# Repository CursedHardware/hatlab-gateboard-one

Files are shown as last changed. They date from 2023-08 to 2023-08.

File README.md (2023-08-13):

# HATLab Gateboard One

— Hackable MT7621(D)AT Reference Board for Geeks.

---

- [docs](docs)
- [OpenWrt] v21.02.5: [patches/openwrt/21.02.5](patches/openwrt/21.02.5)
- [U-boot] v2022.10: [patches/uboot/2022.10](patches/uboot/2022.10)

[OpenWrt]: https://openwrt.org
[U-boot]: https://en.wikipedia.org/wiki/Das_U-Boot

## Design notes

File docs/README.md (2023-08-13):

# Documentation

- Knowledge base: <http://open.hatlab.dbappsecurity.com.cn/gateboard-one> (Chinese)
- [Hardware function](hardware)
- [Schematic diagram](schematic)
- [Electrical parameters](ELECTRICAL.md)
- [Pre-compiled firmware](FIRMWARE.md)
- [WiFi/LTE module](MODULE.md)

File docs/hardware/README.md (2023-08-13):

# Hardware function

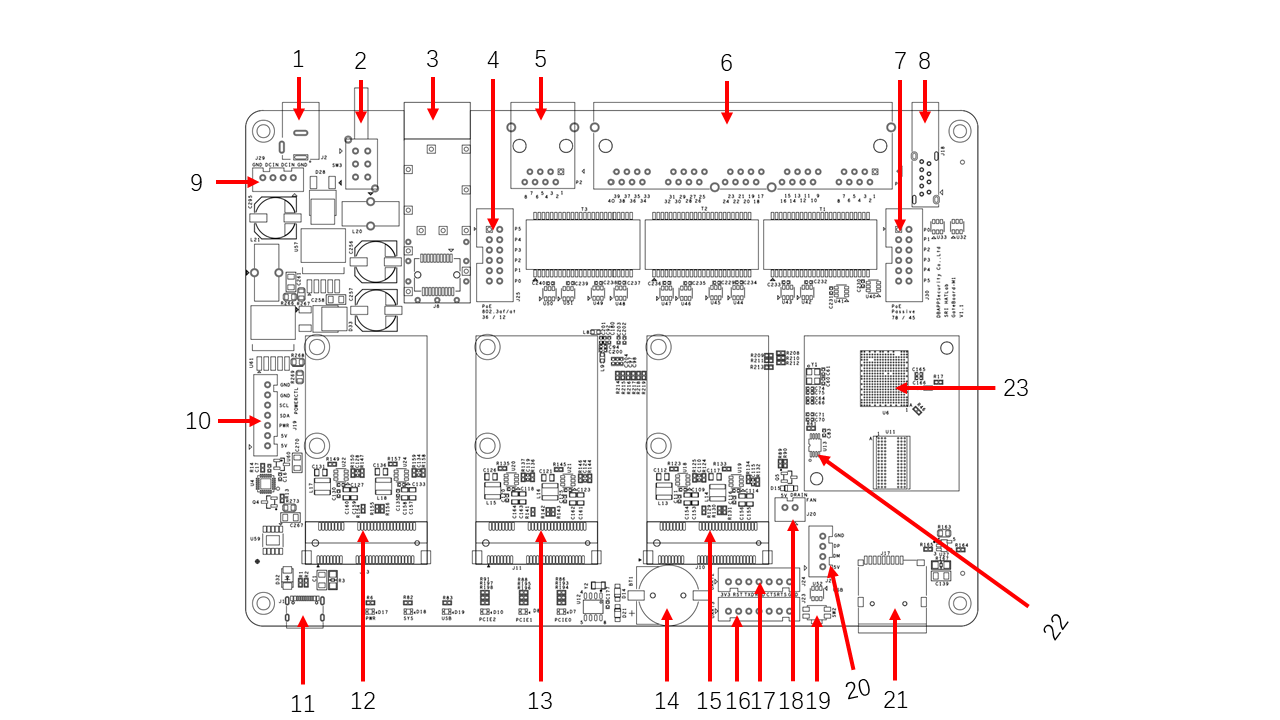
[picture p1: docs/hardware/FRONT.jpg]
Front


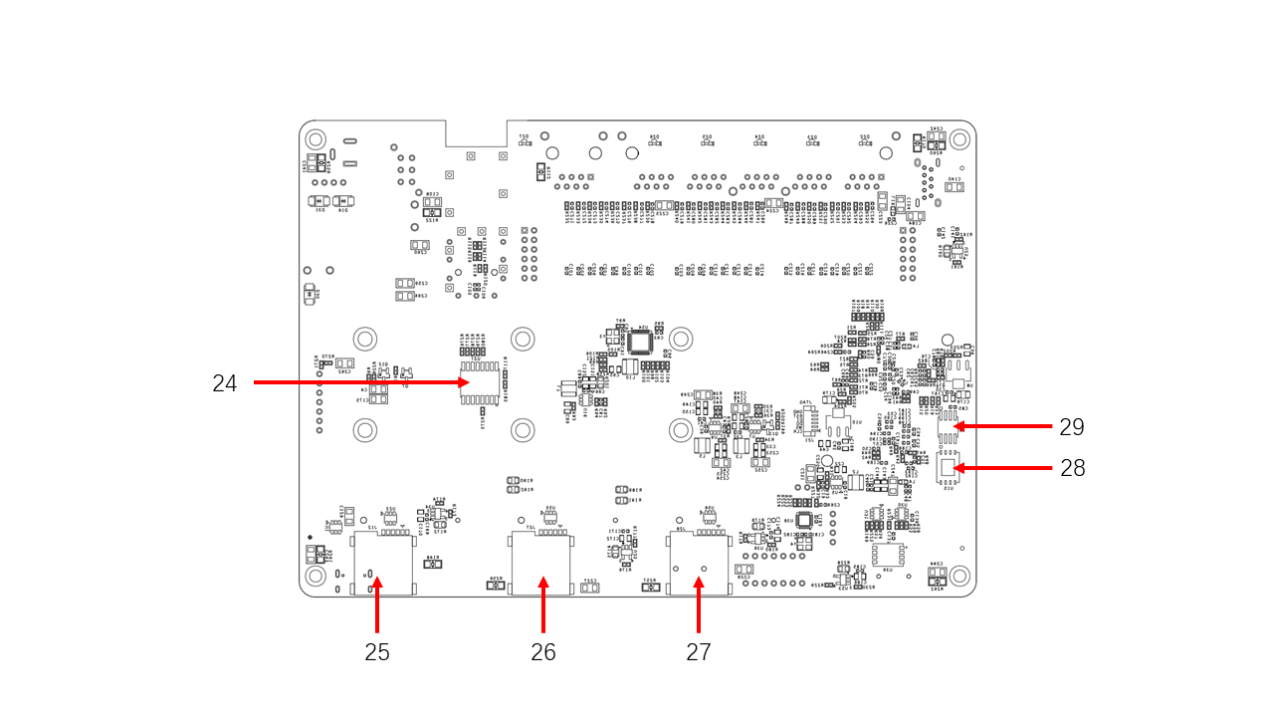
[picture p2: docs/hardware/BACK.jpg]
Back


1. [DC Power]
2. Power Switch
3. [SFP Combo]
4. [PoE IEEE]
5. [RJ45 Combo][SFP Combo]
6. [Ethernet] ports 1-5
7. [PoE Passive]
8. [USB 3.0]
9. External power supply interface
10. Function extension interface
11. Type-C (PD / [Serial])
12. [PCIe2]
13. [PCIe1]
14. RTC Battery (CR1220)
15. [PCIe0]
16. [Full-featured UART] 1
17. [Full-featured UART] 2
18. Fan Power Interface
19. Reset Power
20. Fan Control Interface
21. Pop-up [TF card slot]
22. Temperature Sensor [^temp-sensor]
23. [MT7621AT] Chip
24. GPIO extended chip
25. Pop-up [SIM card slot] 2
26. Pop-up [SIM card slot] 1
27. Pop-up [SIM card slot] 0
28. SPI NAND (Reserved)
29. BIOS NOR [^bios-flash]

[^temp-sensor]: On-board x1 Temperature Sensor, Used to collect the main control temperature.
[^bios-flash]: 512KB SPI Flash

[MT7621AT]: https://deviwiki.com/wiki/MediaTek_MT7621#MT7621AT
[DC Power]: ../schematic/README.md#power
[PoE IEEE]: ../pinout/README.md#poe-ieee
[PoE Passive]: ../pinout/README.md#poe-passive
[SFP Combo]: ../pinout/README.md#sfp
[Ethernet]: ../pinout/README.md#ethernet
[USB 3.0]: ../pinout/README.md#usb-30
[Serial]: ../schematic/README.md#usb-uart
[PCIe0]: ../schematic/README.md#pcie-0-connector
[PCIe1]: ../schematic/README.md#pcie-1-connector
[PCIe2]: ../schematic/README.md#pcie-2-connector
[Full-featured UART]: ../pinout/README.md#uart
[TF card slot]: ../pinout/README.md#tf-slot
[SIM card slot]: ../pinout/README.md#sim-slot

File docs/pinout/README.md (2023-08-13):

# PINOUT

## UART

> The UART Support RS232 / RS485

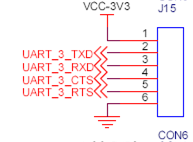
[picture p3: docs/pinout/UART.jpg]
UART


| # | Name |
| --: | --- |
| 1 | UART_3V3 |
| 2 | UART_TX  |
| 3 | UART_RX  |
| 4 | UART_CTS |
| 5 | UART_RTS |
| 6 | UART_GND |

## USB 3.0

> On-board x1 USB 3.0 Interface, Compatible USB 2.0, USB 1.1, Support USB-Hub Extending.

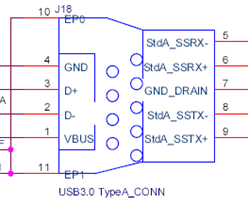
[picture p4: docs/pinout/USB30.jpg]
USB 3.0


| # | Name |
| --: | --- |
| 1 | VBUS |
| 2 | USB_D- |
| 3 | USB_D+ |
| 4 | GND |
| 5 | StdA_SSRX- |
| 6 | StdA_SSRX+ |
| 7 | GND_DRAIN  |
| 8 | StdA_SSTX- |
| 9 | StdA_SSTX+ |

## JTAG

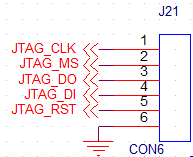
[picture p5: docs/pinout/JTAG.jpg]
JTAG


| # | Name |
| --: | --- |
| 1 | JTAG_CLK |
| 2 | JTAG_MS  |
| 3 | JTAG_DO  |
| 4 | JTAG_DI  |
| 5 | JTAG_RST |
| 6 | GND |

## PCIe

> There are 3 PCIe interfaces on board, all of which support PCIe2.0 x1 specification, and support PCIe function expansion cards such as PCIe to USB, PCIe to SATA, PCIe wired network card, PCIe wireless network card, etc.
>
> The 3 PCIe interfaces all support the expansion of the 4G/LTE module of the USB bus, and are connected with the onboard pop-up SIM card holder
>
> (Note: due to the BUG of the 7621 itself, only 2 modules can work at the same time when the dedicated module is not used).

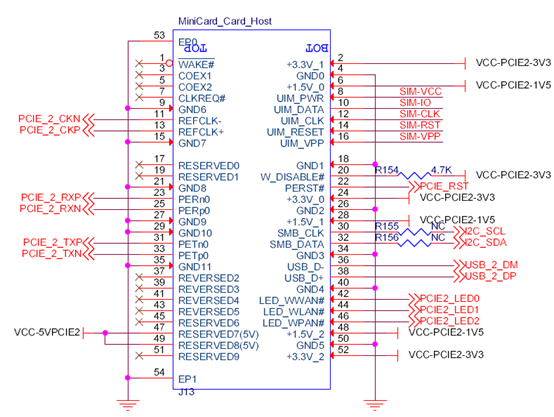
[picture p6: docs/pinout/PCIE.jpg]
PCIE


| # | Name (Standard) | Name (On board) |
| --: | --- | --- |
| 1 | WAKE# | NC |
| 2 | 3.3Vaux | VCC_3V3 |
| 3 | COEX1 | NC |
| 4 | GND | GND |
| 5 | COEX2 | NC |
| 6 | 1.5V | VCC_1V5 |
| 7 | CLKREQ# | NC |
| 8 | UIM_PWR | VCC_SIM |
| 9 | GND | GND |
|  10 | UIM_DATA | SIM_IO |
|  11 | REFCLK- | PCIE_CKN |
|  12 | UIM_CLK | SIM_CLK |
|  13 | REFCLK+ | PCIE_CKP |
|  14 | UIM_RESET | SIM_RESET |
|  15 | GND | GND |
|  16 | UIM_Vpp | SIM_VPP |
|  17 | _Reserved_ | NC |
|  18 | GND | GND |
|  19 | _Reserved_ | NC |
|  20 | W_DISABLE# | PU |
|  21 | GND | GND |
|  22 | PERST# | PCIE_RST |
|  23 | PERn0 | PCIE_RXP |
|  24 | 3.3Vaux | VCC_3V3 |
|  25 | PERp0 | PCIE_RXN |
|  26 | GND | GND |
|  27 | GND | GND |
|  28 | 1.5V | VCC_1.5V |
|  29 | GND | GND |
|  30 | SMB_CLK | I2C_SCL |
|  31 | PETn0 | PCIE_TXP |
|  32 | SMB_DATA | I2C_SDA |
|  33 | PETp0 | PCIE_TXN |
|  34 | GND | GND |
|  35 | GND | GND |
|  36 | USB_D- | USB_D- |
|  37 | GND | GND |
|  38 | USB_D+ | USB_D+ |
|  39 | 3.3Vaux | NC |
|  40 | GND | GND |
|  41 | 3.3Vaux | NC |
|  42 | LED_WWAN# | PCIE_LED0 |
|  43 | GND | NC |
|  44 | LED_WLAN# | PCIE_LED1 |
|  45 | _Reserved_ | NC |
|  46 | LED_WPAN# | PCIE_LED2 |
|  47 | _Reserved_ | VCC_5V |
|  48 | 1.5V | VCC_1.5V |
|  49 | _Reserved_ | VCC_5V |
|  50 | GND | GND |
|  51 | _Reserved_ | NC |
|  52 | 3.3Vaux | VCC_3V3 |

## SFP

> There is one SFP interface with plug-in detection on board, which is a mutually exclusive interface with RJ45 Combo.
>
> Compatible with ordinary GbE fiber optic modules.

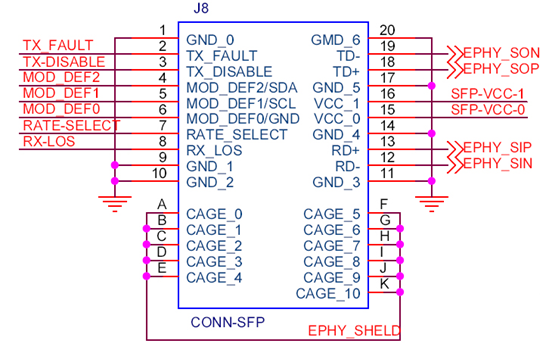
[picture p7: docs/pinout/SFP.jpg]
SFP


| # | Name |
| --: | --- |
| 1 | GND |
| 2 | TX_Fault |
| 3 | TX_disable  |
| 4 | MOD-DEF2 |
| 5 | MOD-DEF1 |
| 6 | MOD-DEF0 |
| 7 | Rate_Select |
| 8 | Rate_LOS |
| 9 | GND |
|  10 | GND |
|  11 | GND |
|  12 | EPHY_SIN |
|  13 | EPHY_SIP |
|  14 | GND |
|  15 | SFP_VCC0 |
|  16 | SFP_VCC1 |
|  17 | GND |
|  18 | EPHY_SOP |
|  19 | EPHY_SON |
|  20 | GND |

## Ethernet

> There are 6x GbE RJ45 network ports on board, all complying with IEEE1588-2008.

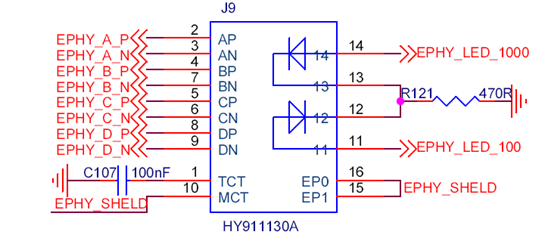
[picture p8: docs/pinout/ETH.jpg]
Ethernet


| # | Name |
| --: | --- |
| 1 | TCT |
| 2 | EPHY_A_P |
| 3 | EPHY_A_N |
| 4 | EPHY_B_P |
| 5 | EPHY_C_P |
| 6 | EPHY_C_N |
| 7 | EPHY_B_N |
| 8 | EPHY_D_P |
| 9 | EPHY_D_N |
|  10 | MCT |
|  11 | LED_YELLOW |
|  12 | GND |
|  13 | GND |
|  14 | LED_GREEN  |
|  15 | EPHY_SHELD |
|  16 | EPHY_SHELD |

## TF Slot

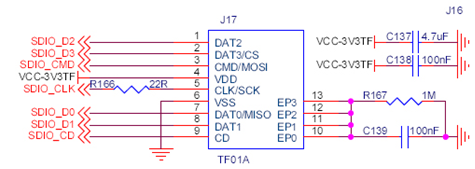
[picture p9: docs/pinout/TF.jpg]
TF Slot


| # | Name |
| --: | --- |
| 1 | SDIO_D2  |
| 2 | SDIO_D3  |
| 3 | SDIO_CMD |
| 4 | VCC_3V3  |
| 5 | SDIO_CLK |
| 6 | GND |
| 7 | SDIO_D0  |
| 8 | SDIO_D1  |
| 9 | SDIO_CD  |
|  10 | EP |
|  11 | EP |
|  12 | EP |
|  13 | EP |

## SIM Slot

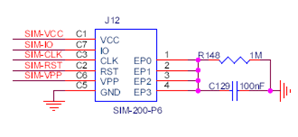
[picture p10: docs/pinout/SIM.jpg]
SIM Slot


| # | Name |
| --: | --- |
| 1 | SIM_VCC |
| 2 | SIM_IO  |
| 3 | SIM_CLK |
| 4 | SIM_RST |
| 5 | SIM_VPP |
| 6 | GND |

## Power Control

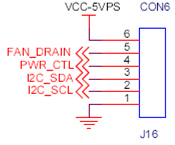
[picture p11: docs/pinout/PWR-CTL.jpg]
Power Control


| # | Name |
| --: | --- |
| 1 | GND |
| 2 | I2C_SCL |
| 3 | I2C_SDA |
| 4 | PWR_CTL |
| 5 | FAN_DRAIN |
| 6 | VCC |

\* PWR_CTL: high level is Power ON, low level is Power OFF.

## PoE IEEE

> Standard: 802.3af / 802.3at

## PoE Passive

> Standard: Passive

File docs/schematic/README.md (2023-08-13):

# Schematic diagram

## Power

> On-board x1 DC Power, Support 9-19V DC input.

No Public

## USB UART

> The USB Serial is [CH340N] chip

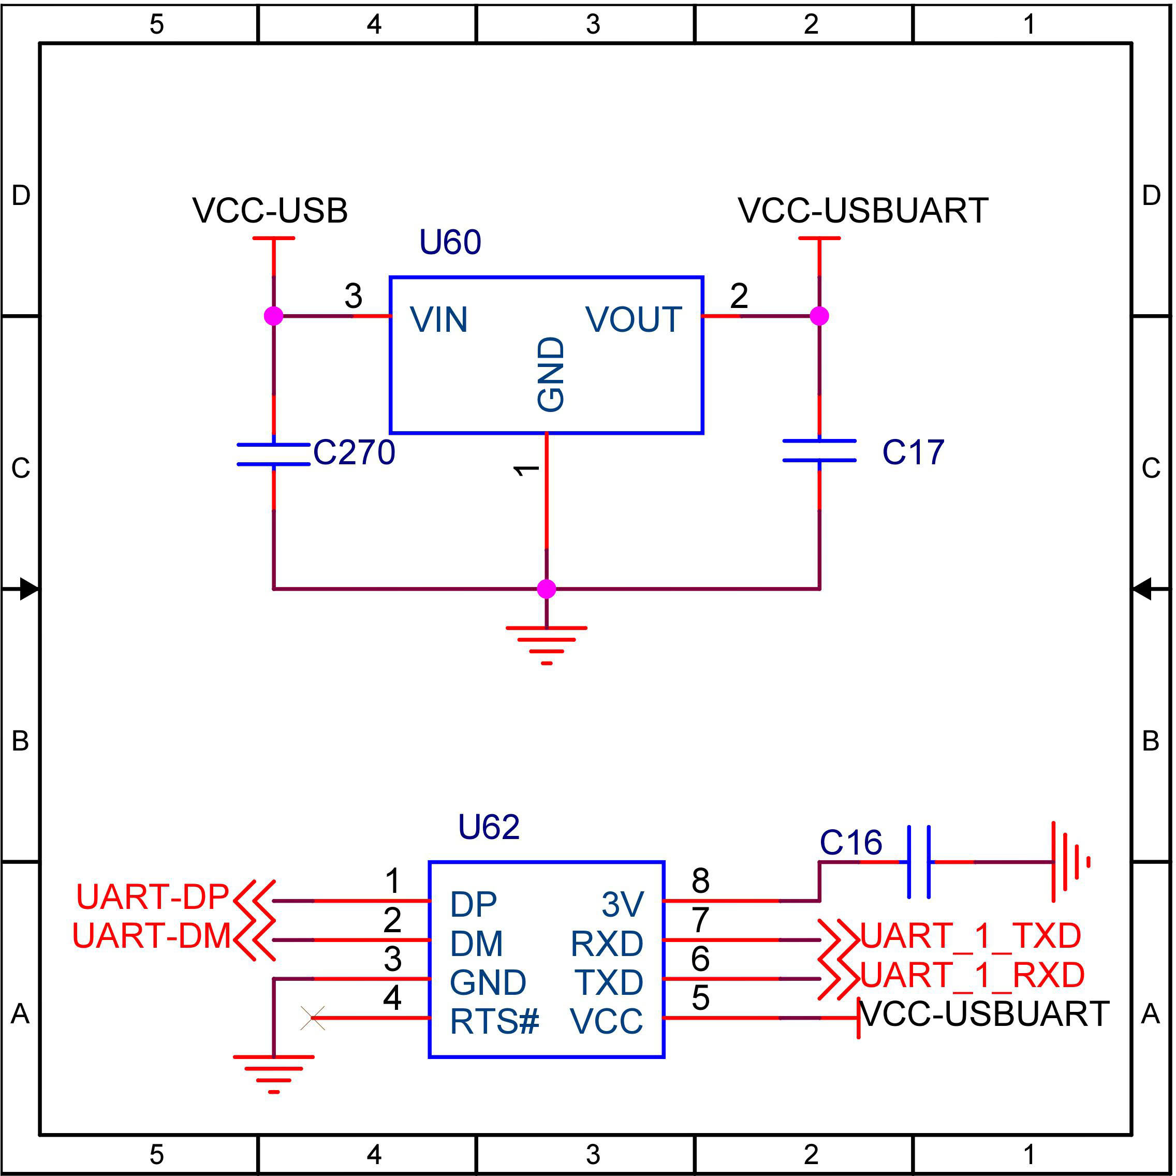
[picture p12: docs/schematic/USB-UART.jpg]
USB-UART


## SoC Config

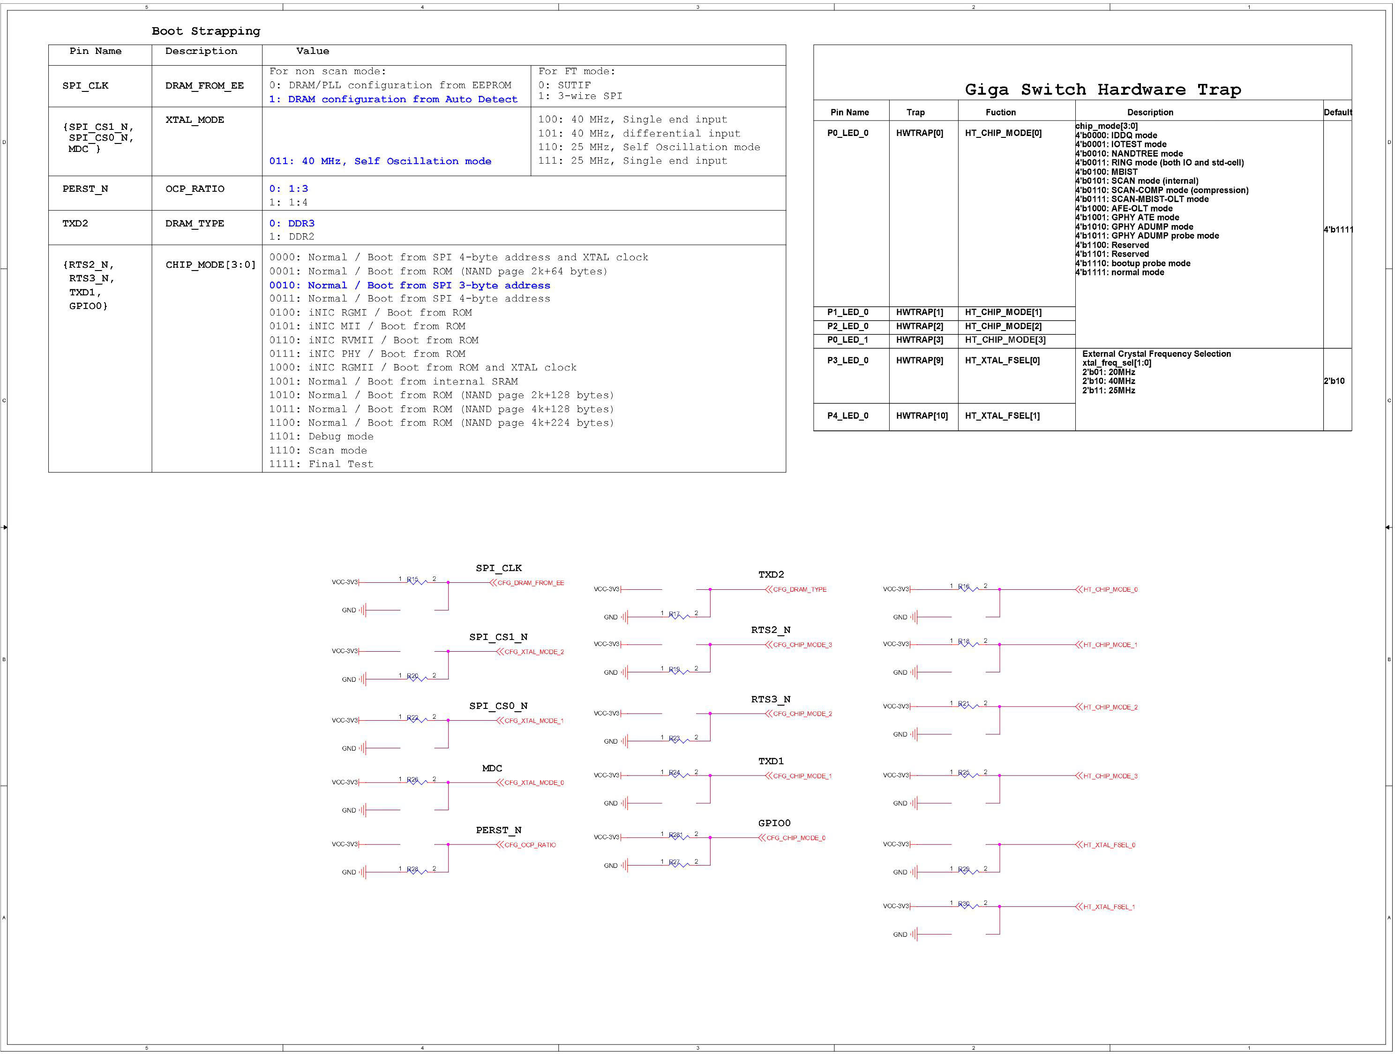
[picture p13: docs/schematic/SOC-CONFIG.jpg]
SOC-CONFIG


## SoC Power

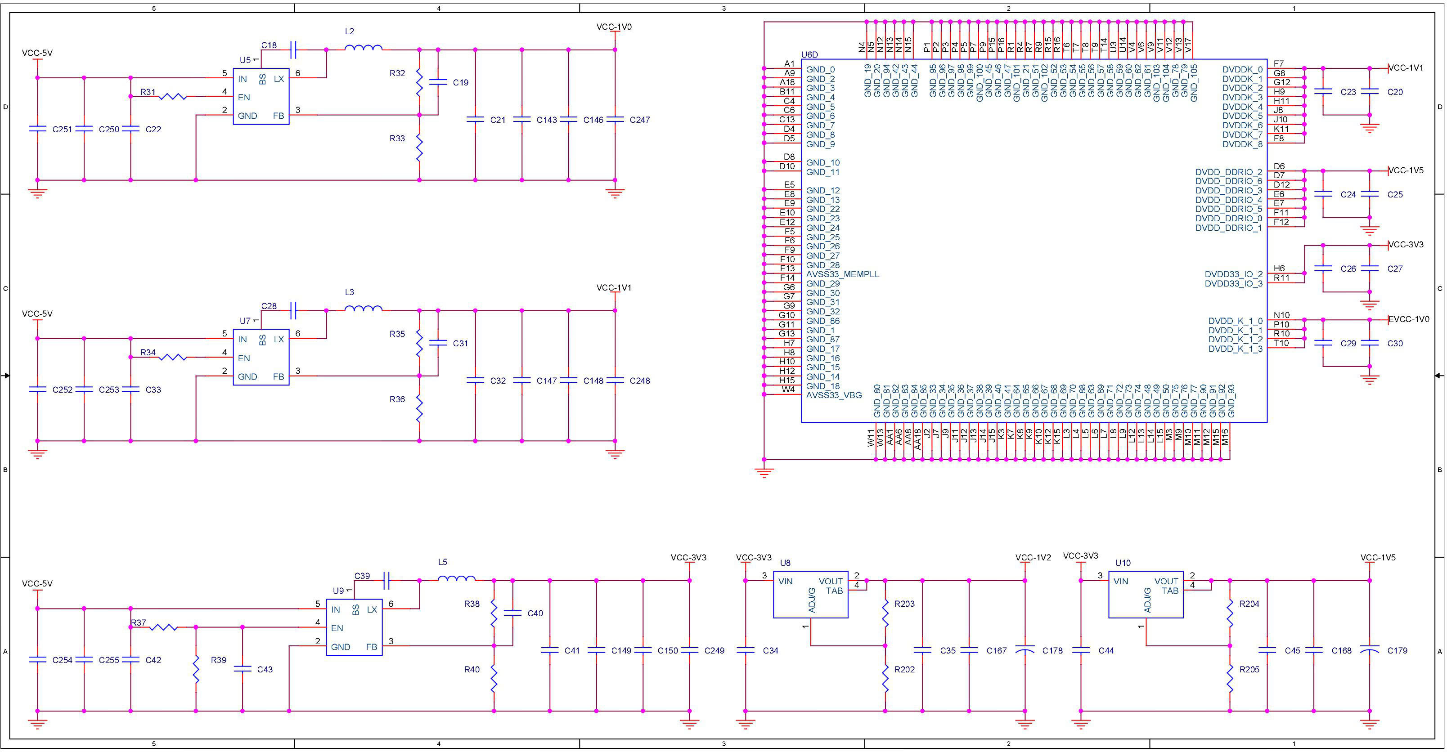
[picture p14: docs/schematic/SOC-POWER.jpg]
SOC-POWER


## SoC Memory

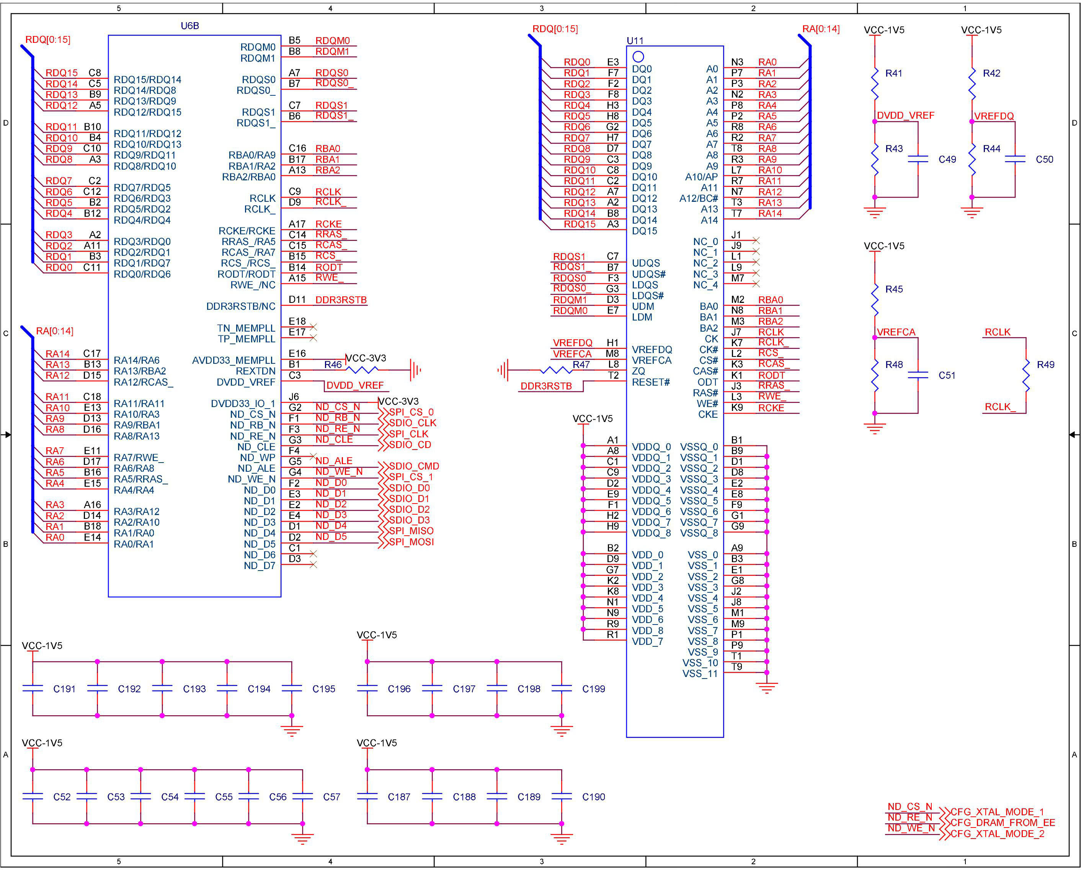
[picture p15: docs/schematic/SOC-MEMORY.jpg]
SOC-MEMORY


## SoC System/USB/PCIe

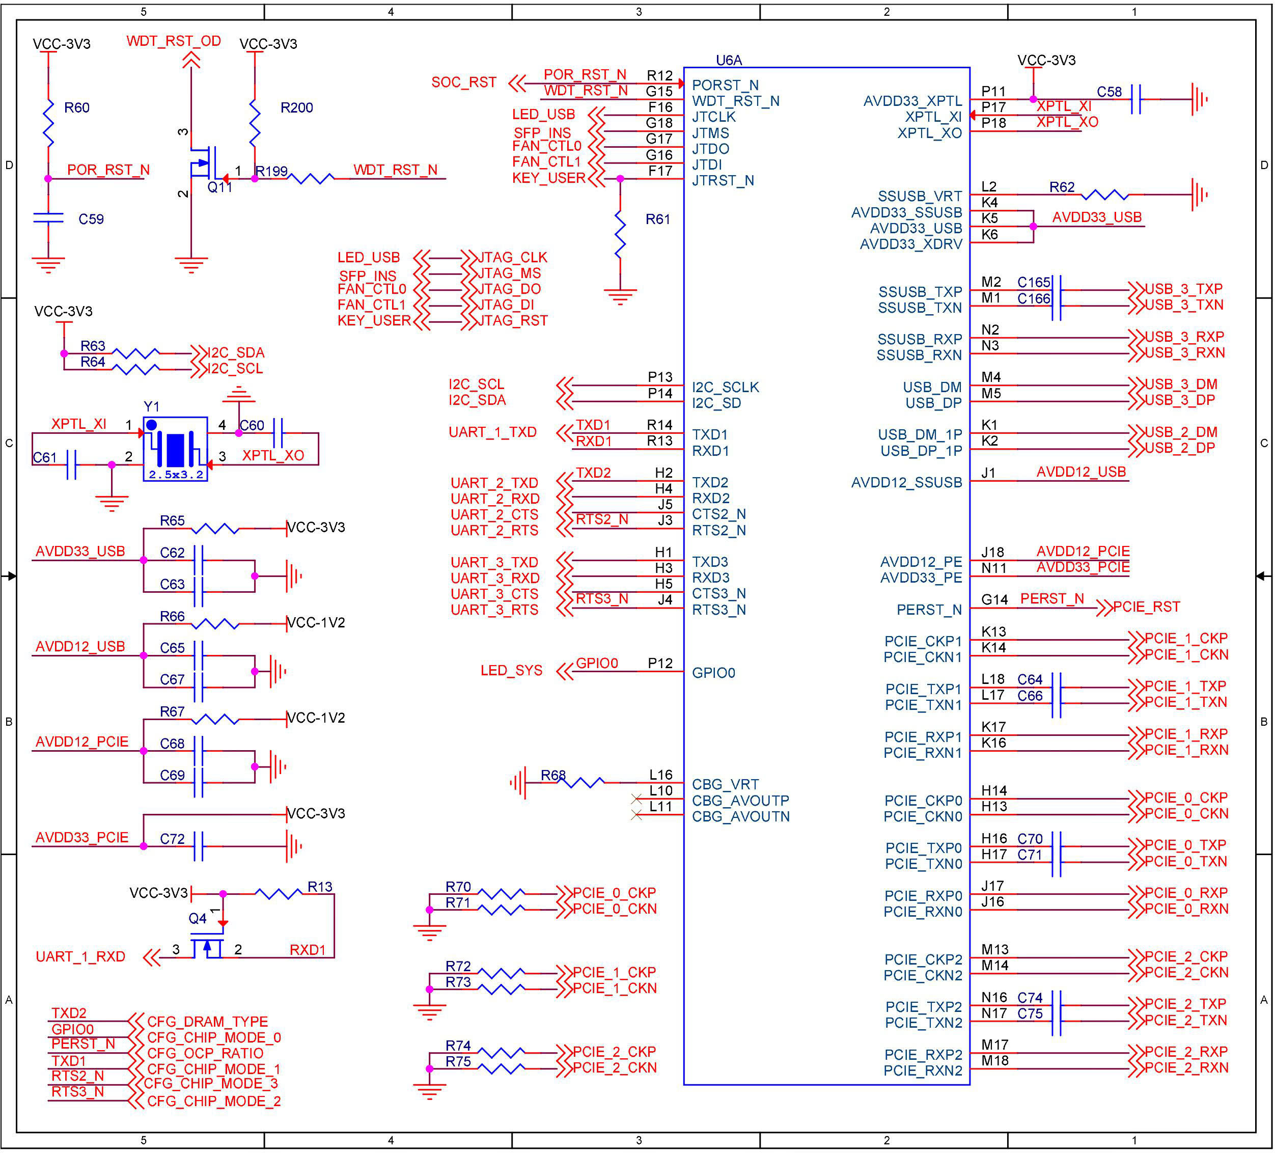
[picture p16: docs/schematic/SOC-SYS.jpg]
SOC-SYS


## SoC GSwitch/RGMII

No Public

## Perhipial

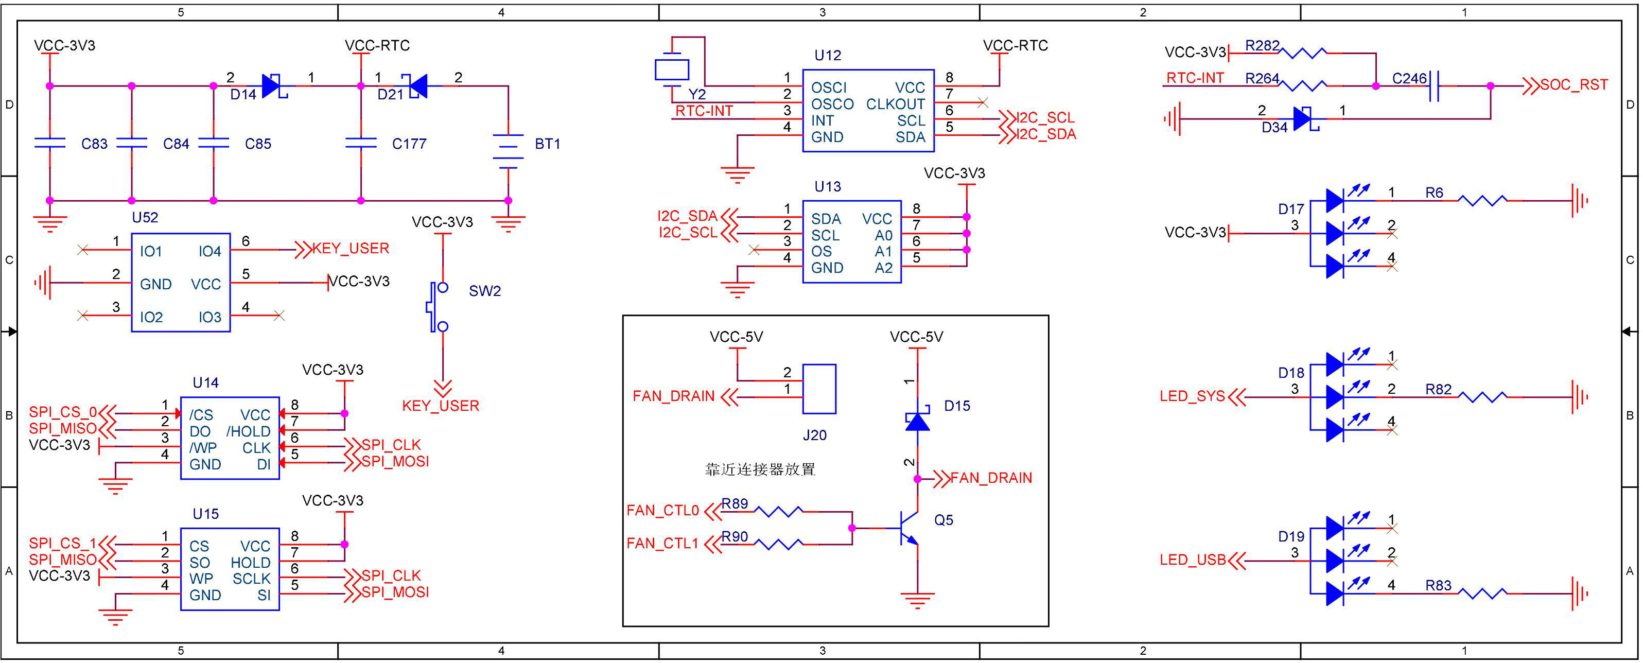
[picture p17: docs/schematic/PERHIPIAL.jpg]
PERHIPIAL


## External PHY

No Public

## USB Hub

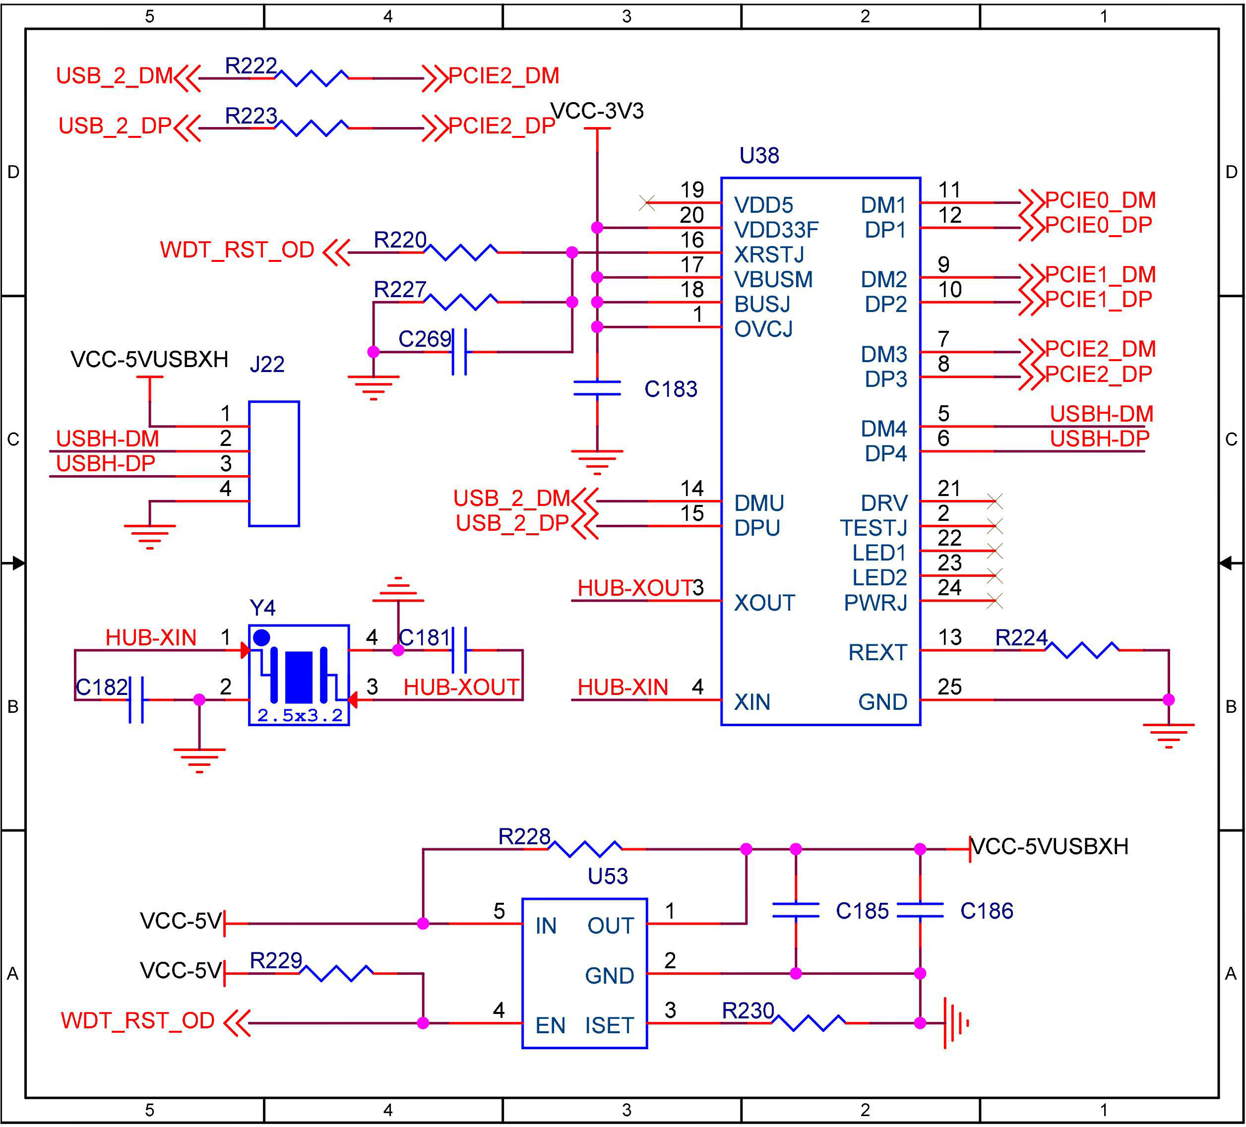
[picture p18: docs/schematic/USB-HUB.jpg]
USB-HUB


## Network (Connector)

No Public

## PCIe 0 (Connector)

> PINOUT: [PCIe]

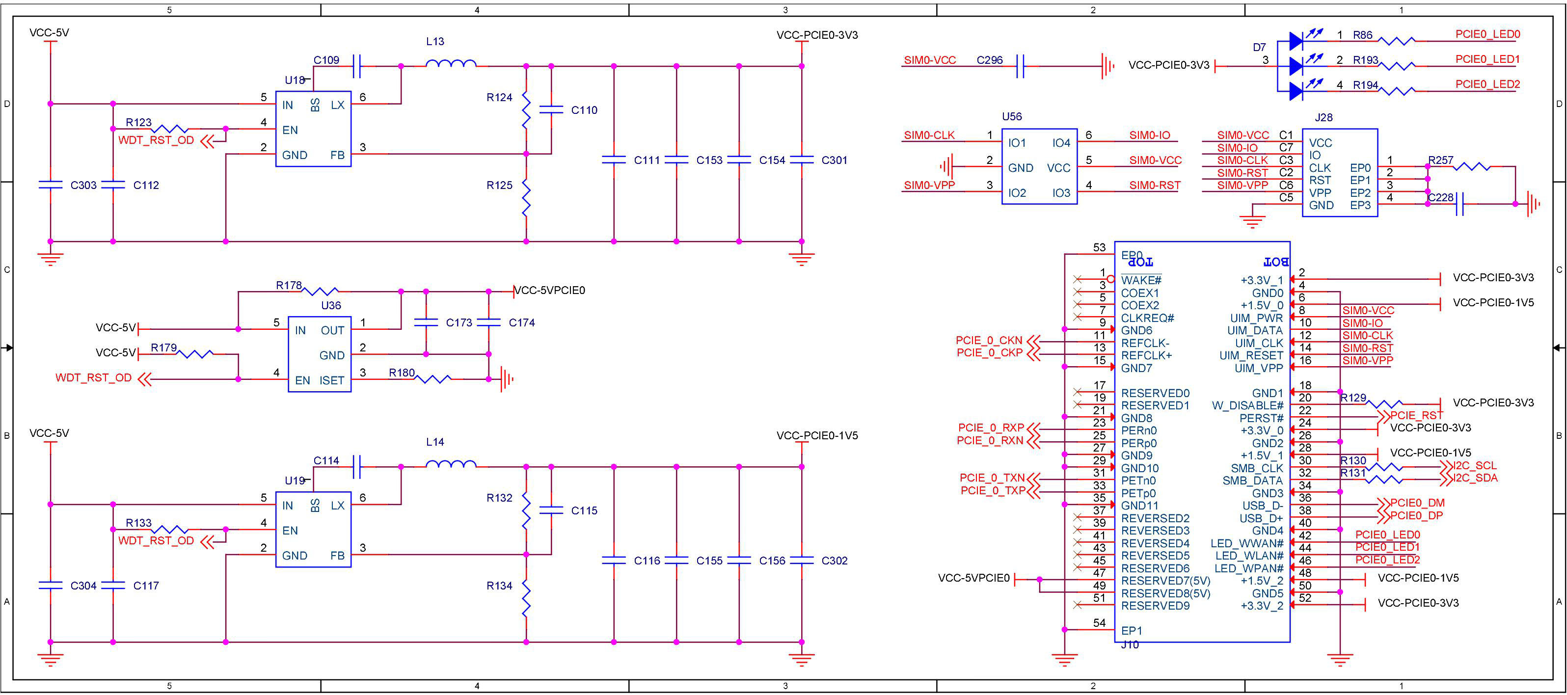
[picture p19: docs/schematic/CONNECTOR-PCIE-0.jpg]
CONNECTOR-PCIE-0


## PCIe 1 (Connector)

> PINOUT: [PCIe]

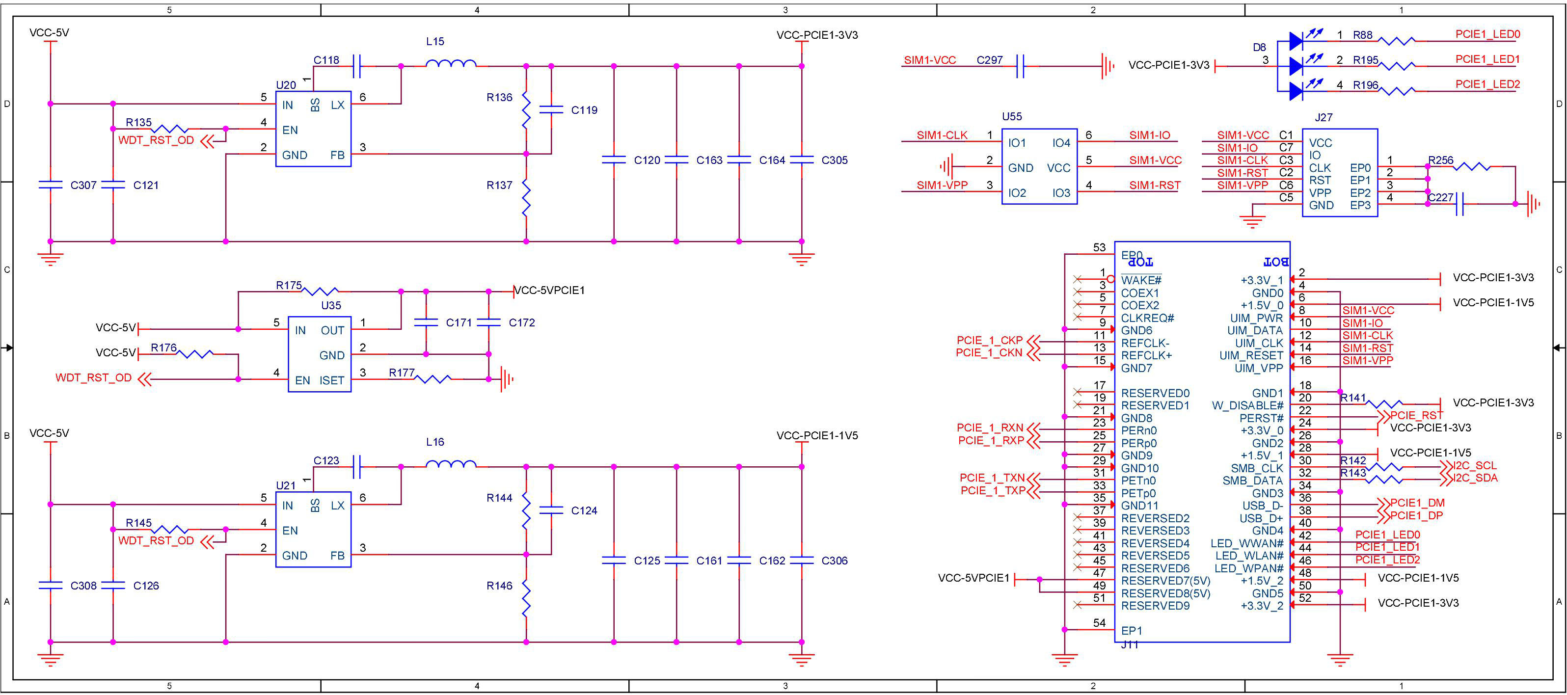
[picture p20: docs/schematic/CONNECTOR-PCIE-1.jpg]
CONNECTOR-PCIE-1


## PCIe 2 (Connector)

> PINOUT: [PCIe]

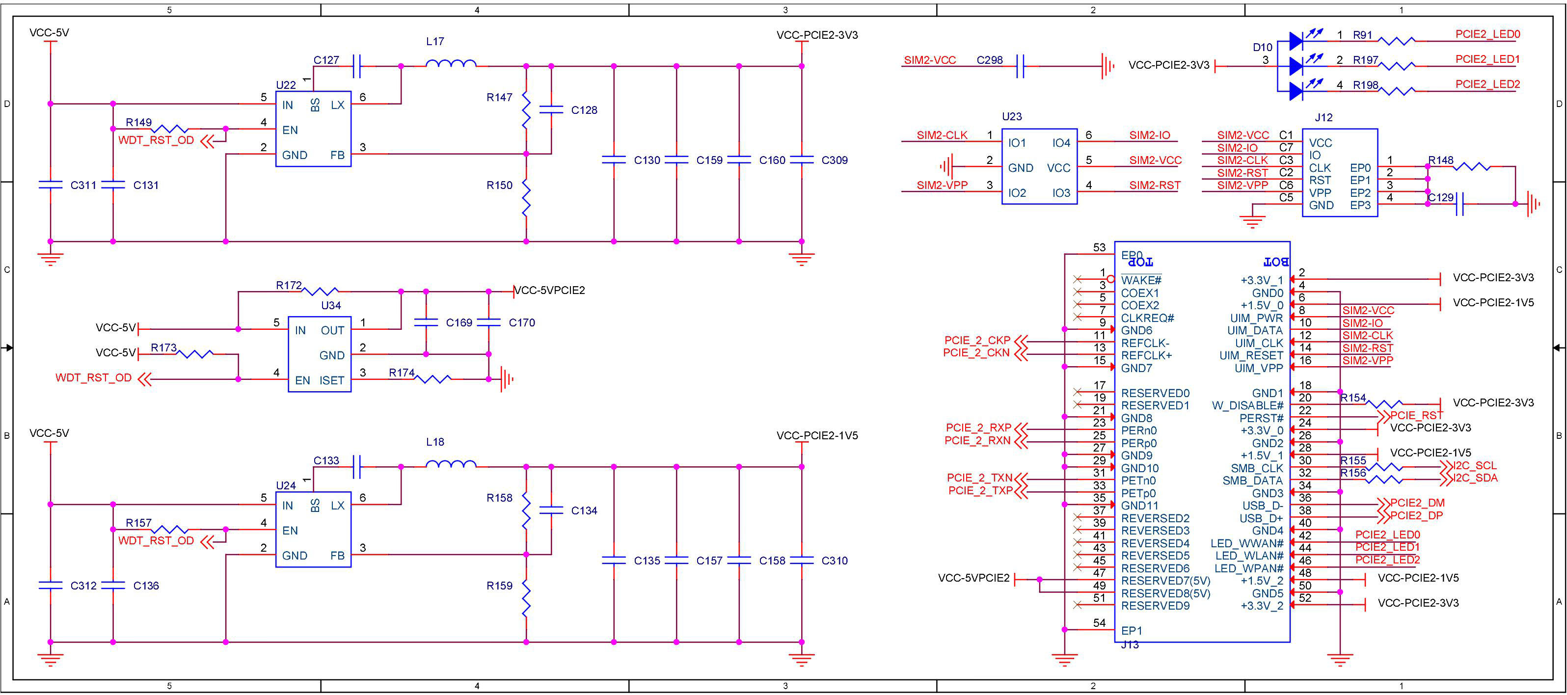
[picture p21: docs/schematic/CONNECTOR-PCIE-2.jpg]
CONNECTOR-PCIE-2


## Misc (Connector)

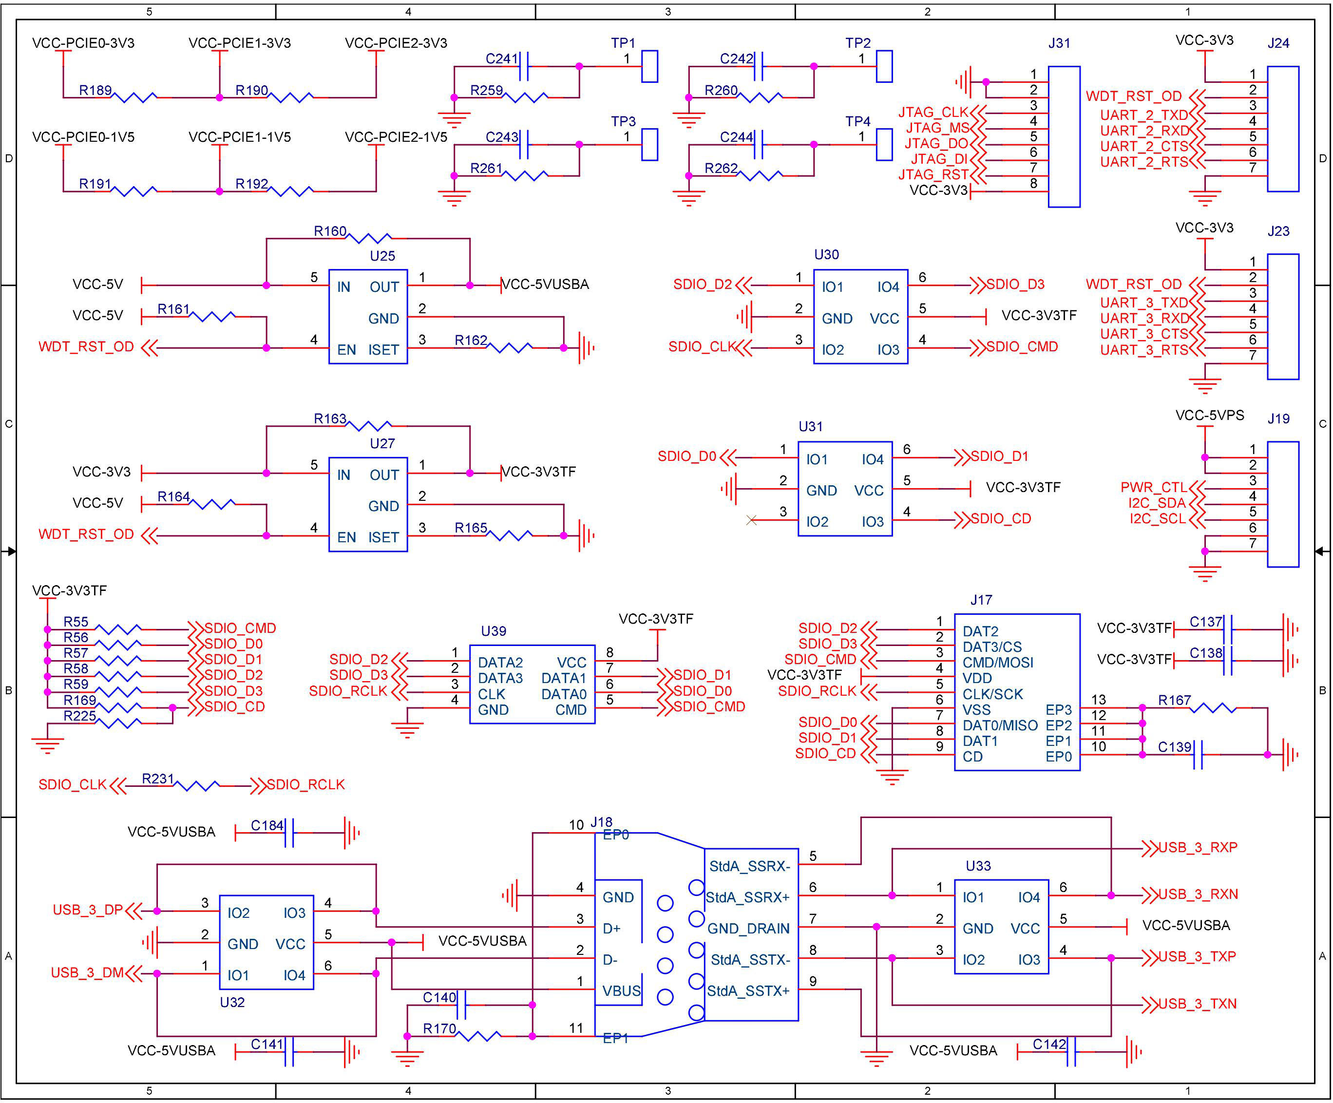
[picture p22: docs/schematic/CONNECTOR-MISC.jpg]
CONNECTOR-MISC


[CH340N]: https://www.wch-ic.com/products/CH340.html
[PCIe]: ../pinout/README.md#pcie

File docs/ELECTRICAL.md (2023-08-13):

# Electrical parameters

| Unit | Name | Parameter | IO  |  Min | Typical | Max |
| ---: | --- | ---: | --- | ---: | ---: | ----: |
|  _V_ | TYPE_C_IN | Type-C | I | 3.90 | 5.00 | 24.00 |
|  _V_ | DC_IN | DC | I | 4.00 | 12.00 | 24.00 |
|  _V_ | PS | System main | | 4.95 | 5.00 |  5.10 |
|  _V_ | UART | UART | O | 3.20 | 3.30 |  3.40 |
|  _V_ | USB | USB | O | 4.50 | 5.00 |  5.10 |
|  _V_ | SFP | SFP | O | 3.25 | 3.30 |  3.39 |
|  _V_ | PCIe_1.5  | PCIe 1V5 | O | 1.48 | 1.50 |  1.55 |
|  _V_ | PCIe_3.3  | PCIe 3V3 | O | 3.58 | 3.60 |  3.69 |
|  _V_ | PCIe_5 | PCIe 5V0 | O | 4.50 | 5.00 |  5.10 |
|  _V_ | SIM | SIM Card Slot | O | 1.80 | |  3.30 |
|  _V_ | TF |  TF Card Slot | O | 3.20 | 3.30 |  3.40 |
|  _I_ | TYPE_C_IN | Type-C | I | | | |
|  _I_ | DC_IN | DC | I | | | |
|  _I_ | PS | System main | | | | |
|  _I_ | UART | UART | O | | | |
|  _I_ | USB | USB | O | | | |
|  _I_ | SFP | SFP | O | | | |
|  _I_ | PCIe_1.5  | PCIe 1V5 | O | | | |
|  _I_ | PCIe_3.3  | PCIe 3V3 | O | | | |
|  _I_ | PCIe_5 | PCIe 5V0 | O | | | |
|  _I_ | SIM | SIM Card Slot | O | | | |
|  _I_ | TF |  TF Card Slot | O | | | |

- I: Input
- O: Output

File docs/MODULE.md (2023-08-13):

# WiFi/LTE module

## WiFi module

- Atheros AR9382
- Atheros AR9287
- More see [Table of Hardware: WLAN driver](https://openwrt.org/toh/views/toh_admin_wlandriver)

## LTE module

> Non-OEM LTE module, needed shield top surface pinout

- Quectel EC20
- More see [Table of Hardware: LTE Modem supported](https://openwrt.org/toh/views/toh_lte_modem_supported)

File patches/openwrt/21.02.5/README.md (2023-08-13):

# OpenWrt 21.02.5 Patches

Baseline: <https://github.com/openwrt/openwrt/tree/v21.02.5>

Official Modified OpenWrt source: <https://github.com/DasSecurity-HatLab/openwrt>

Pre-compiled firmware: <http://open.hatlab.dbappsecurity.com.cn/gateboard-one/repo/>

## Apply Patches

```bash
git clone --branch=v21.02.5 https://github.com/openwrt/openwrt.git --depth 1
cd openwrt

# apply patch
git apply patches/openwrt/21.02.5/0001-add-hatlab-gateboard-one.patch

# install feeds
./scripts/feeds update -a
./scripts/feeds install -a

# make menu config
#   Target System:
#     MediaTek Ralink MIPS
#     MT7621 based board
#     HATLab GateBoard-One
make menuconfig

# make build
make
```

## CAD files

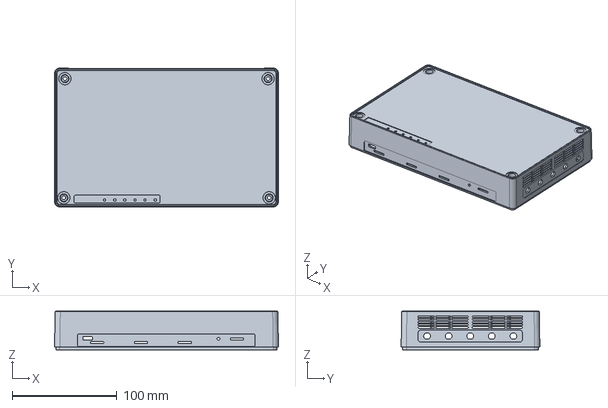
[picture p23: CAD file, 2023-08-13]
docs/shell/1-top.stp
214.0 x 132.6 x 37.0 mm

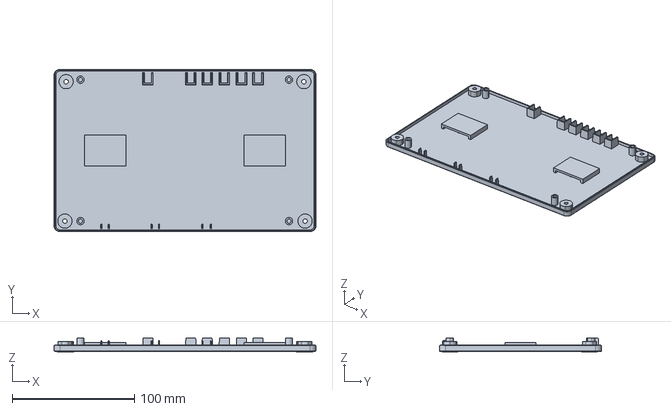
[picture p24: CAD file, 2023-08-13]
docs/shell/2-bottom.stp
214.0 x 132.6 x 11.1 mm

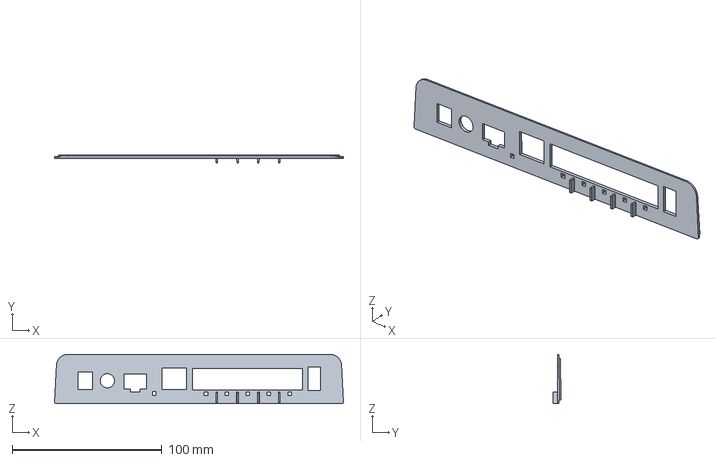
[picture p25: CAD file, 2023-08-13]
docs/shell/3-io.stp
193.0 x 5.50 x 32.8 mm

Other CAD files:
docs/shell/1-top.stl
docs/shell/2-bottom.stl
docs/shell/3-io.stl
